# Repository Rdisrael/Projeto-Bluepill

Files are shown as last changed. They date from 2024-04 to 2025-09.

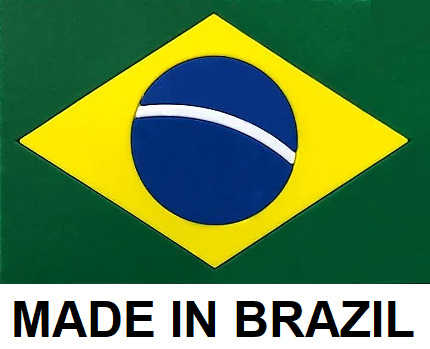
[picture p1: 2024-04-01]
ShieldBluepill V2/imagens e template/imagens/Brazil.jpg

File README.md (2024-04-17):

# PCB SHIELD BLUEPILL



# Resumo
Projeto idealizado com o objetivo de auxiliar as aulas de microcontroladores do IFSP-GRU. Por meio da integração de diversos módulos, componentes e protocolos de comunicação em apenas uma placa de circuito impresso, será possível um aprendizado mais rápido e gradual para os alunos.

# Documentação
https://docs.google.com/spreadsheets/d/1qsbzq-tmwSNhySCmtm99sBOb9c8ssFgKAU8AfdciUCU/edit?usp=sharing

*Salve o projeto no disco local(C:) para que todos os componentes e modelos 3D sejam automaticante carregados*

# Autores

**Rogério Dantas**

https://www.linkedin.com/in/roger-dantas-b04025137/

**Israel R. Dutra**

www.linkedin.com/in/israel-rodrigues-dutra-6947281a0

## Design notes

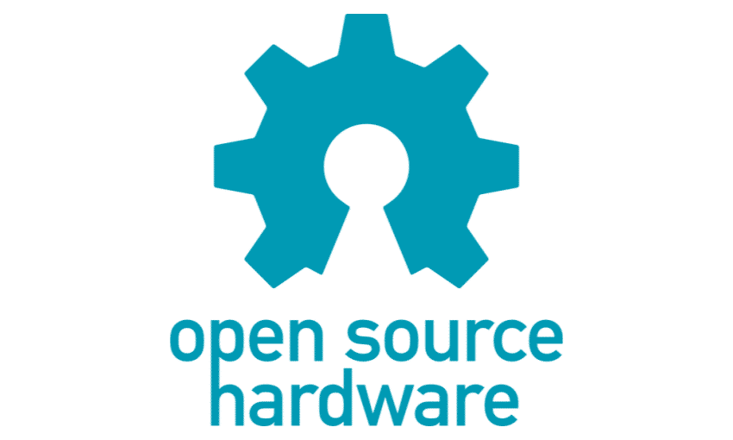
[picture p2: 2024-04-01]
ShieldBluepill V2/imagens e template/imagens/openhardware-destaque-850x510.png

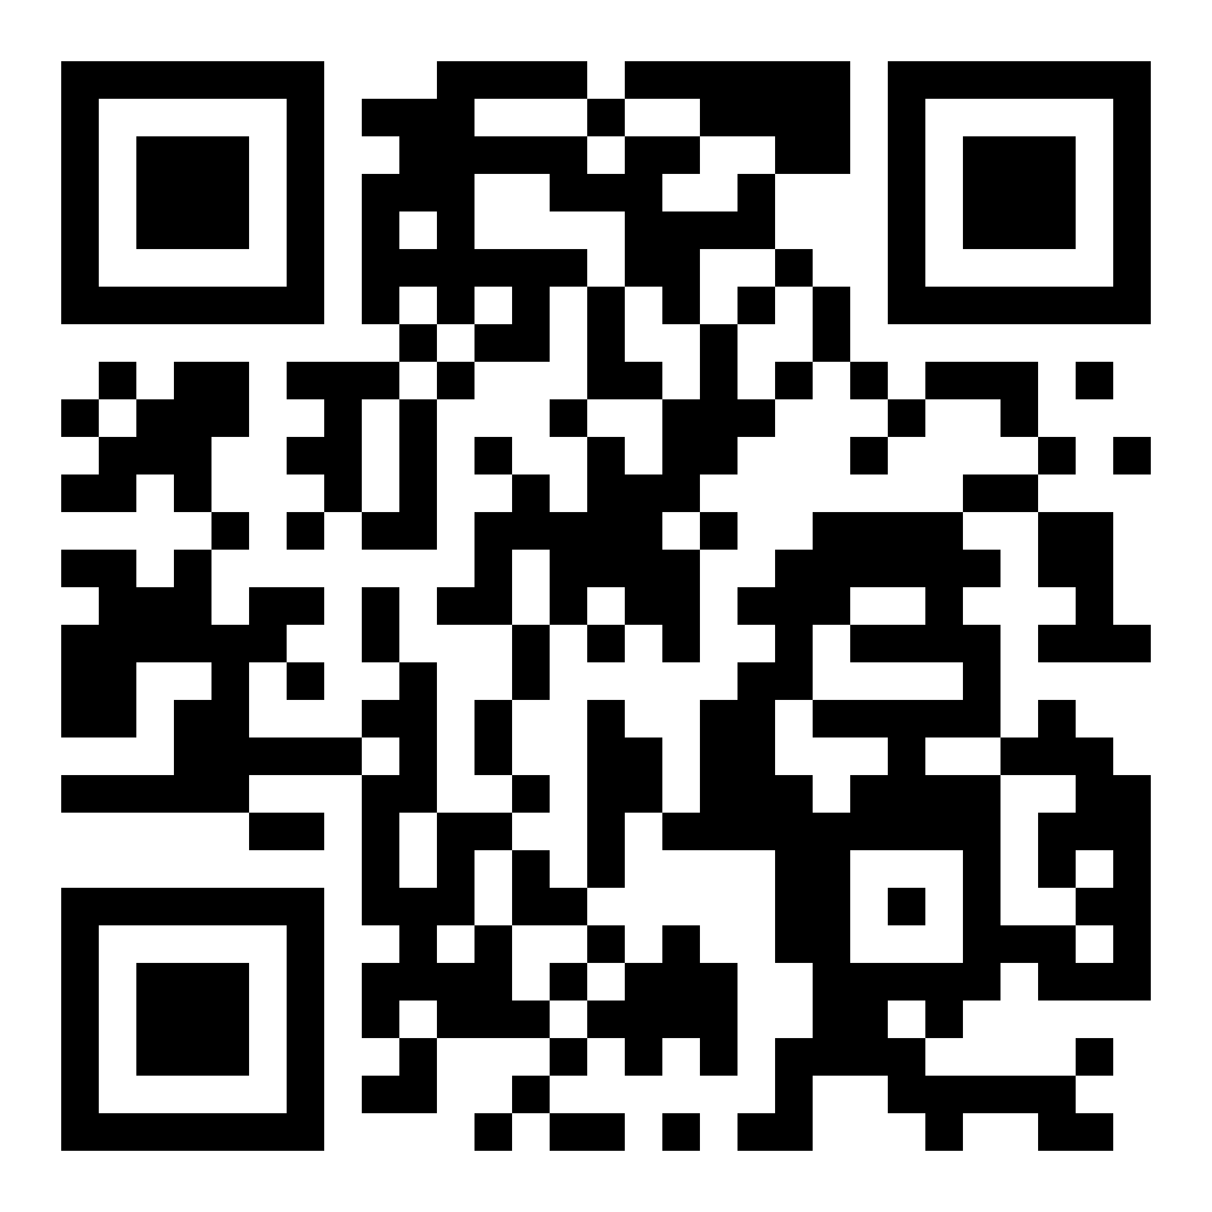
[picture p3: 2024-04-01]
ShieldBluepill V2/imagens e template/imagens/Bluepill GIT.png

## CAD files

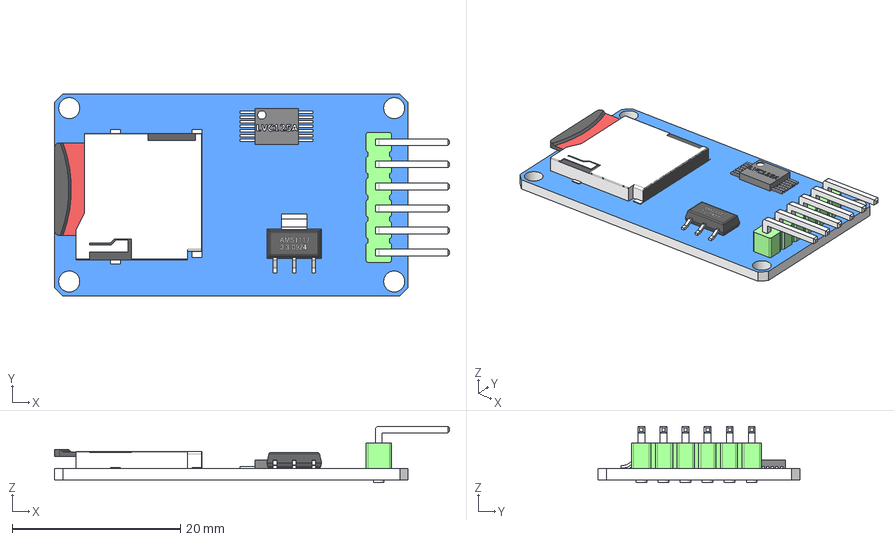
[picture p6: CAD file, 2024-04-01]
ShieldBluepill V2/Simbolo, pegada e modelo 3D/Modelos 3D/MicroSD Reader Assembly.stp
46.9 x 24.0 x 6.70 mm
sdreader
AMS1117
card sd

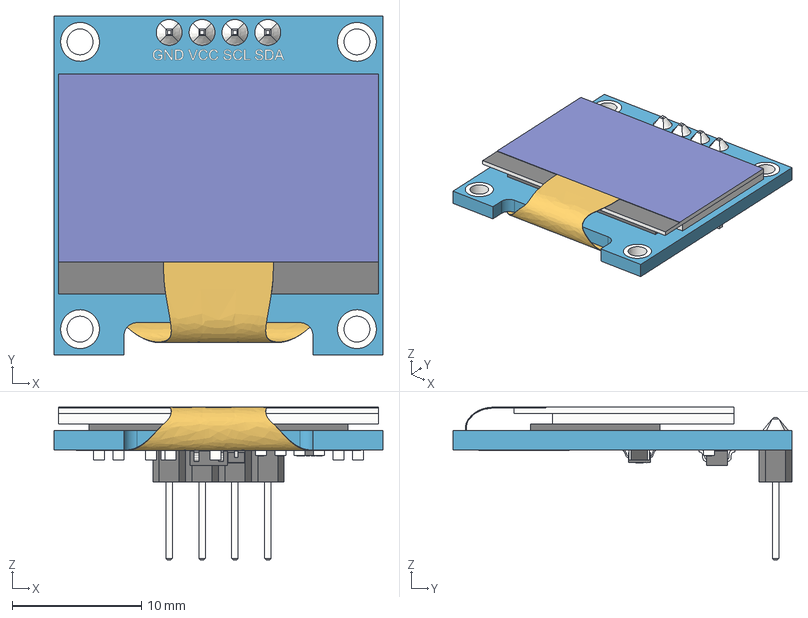
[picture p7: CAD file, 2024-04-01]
ShieldBluepill V2/Simbolo, pegada e modelo 3D/Modelos 3D/SSD1306_OLED_Display(128x64).step
25.4 x 26.2 x 11.8 mm
board
screen
pin_header
soldering
smd_capacitor
smd_capacitor (1)
914_smd_resistor
472_smd_resistor x 3
t4_smd_diode
smd_capacitor (2)
smd_capacitor (3)
smd_capacitor (4)
smd_capacitor (5)
smd_capacitor (6)
472_smd_resistor (1)
SOT-23_XC6206 v3
smd_capacitor (7)
flat_cable

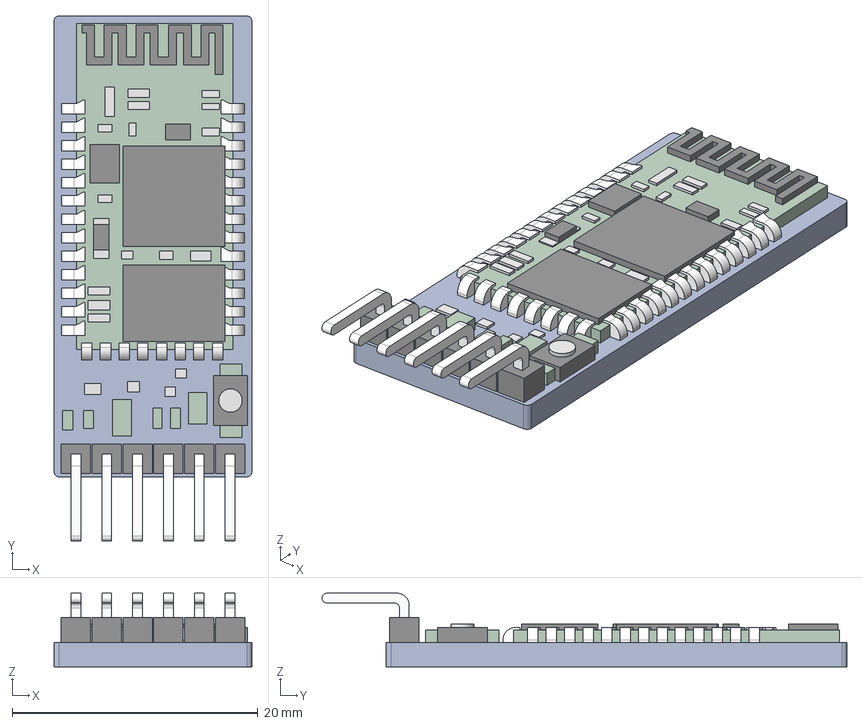
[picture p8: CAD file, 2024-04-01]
ShieldBluepill V2/Simbolo, pegada e modelo 3D/Modelos 3D/HC_05 Blue Tooth Module.stp
16.1 x 42.7 x 6.00 mm

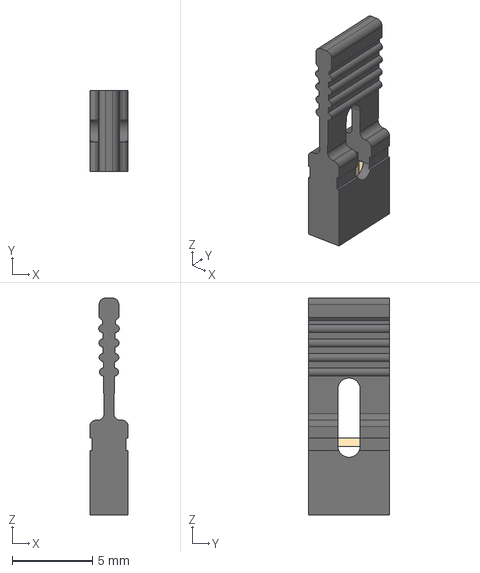
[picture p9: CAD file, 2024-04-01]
ShieldBluepill V2/Simbolo, pegada e modelo 3D/Modelos 3D/AKSPLTG-BLACK.stp
2.39 x 5.05 x 13.5 mm

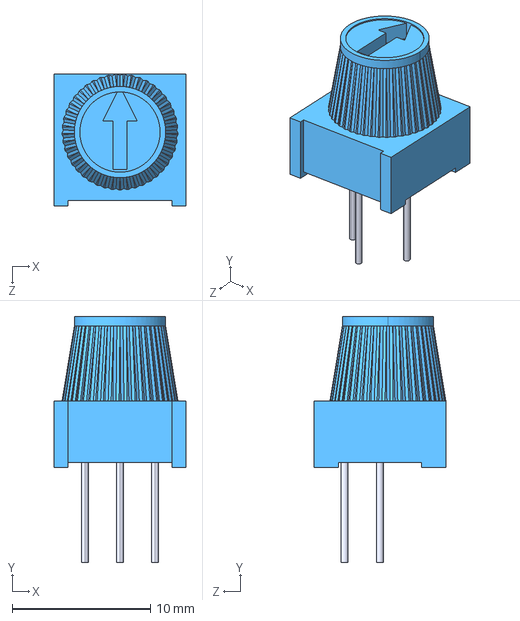
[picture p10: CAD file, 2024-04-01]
ShieldBluepill V2/Simbolo, pegada e modelo 3D/Modelos 3D/Potenciometro.STEP
9.53 x 17.8 x 9.53 mm

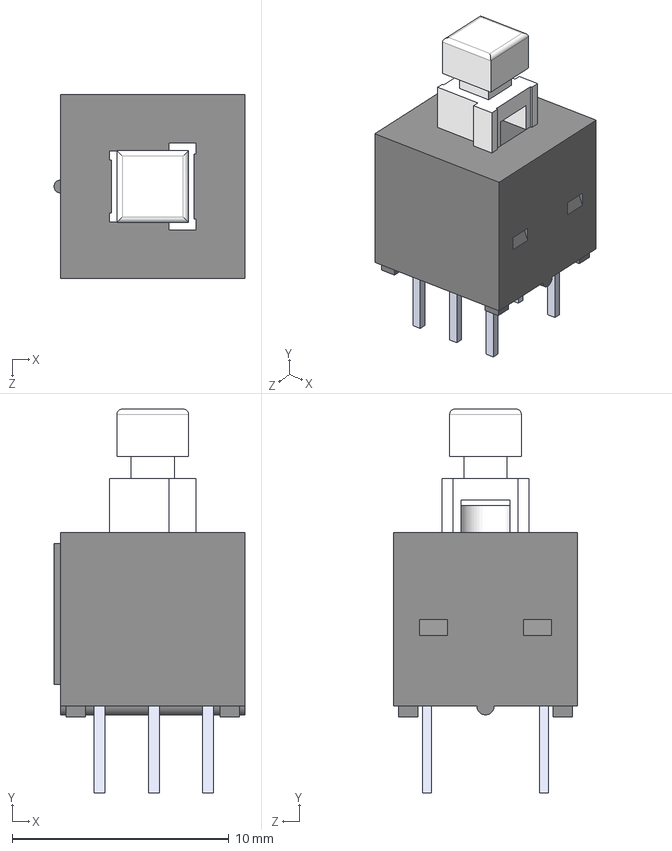
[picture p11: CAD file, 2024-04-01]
ShieldBluepill V2/Simbolo, pegada e modelo 3D/Modelos 3D/Botão com retenção.step
8.80 x 17.7 x 8.50 mm

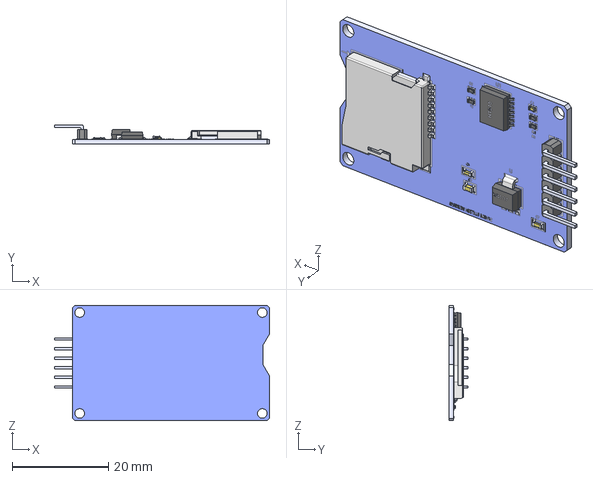
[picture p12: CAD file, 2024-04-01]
ShieldBluepill V2/Simbolo, pegada e modelo 3D/Modelos 3D/leitor microsd.step
44.7 x 4.00 x 24.0 mm

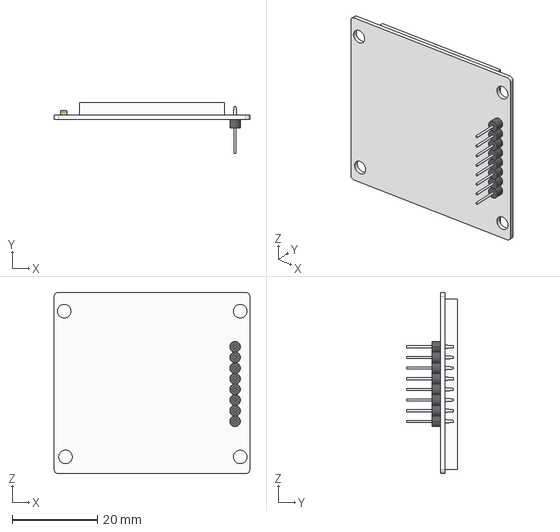
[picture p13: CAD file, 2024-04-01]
ShieldBluepill V2/Simbolo, pegada e modelo 3D/Modelos 3D/Nokia LCD.stp
46.0 x 12.0 x 42.5 mm

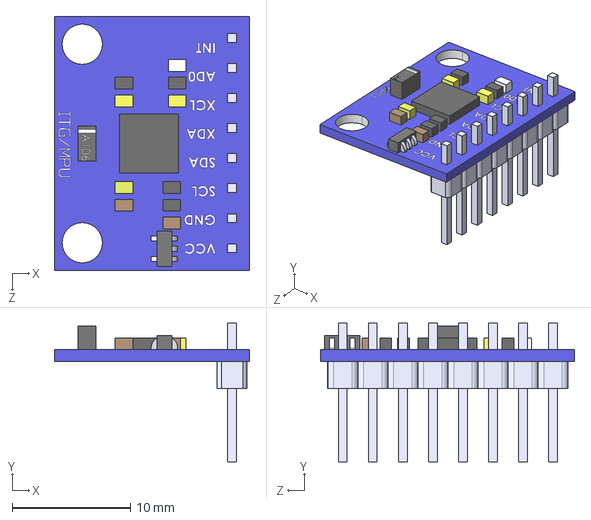
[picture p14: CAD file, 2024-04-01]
ShieldBluepill V2/Simbolo, pegada e modelo 3D/Modelos 3D/ITG-MPU.STEP
16.5 x 11.8 x 21.5 mm
8 Header-Pin
Placa_Base

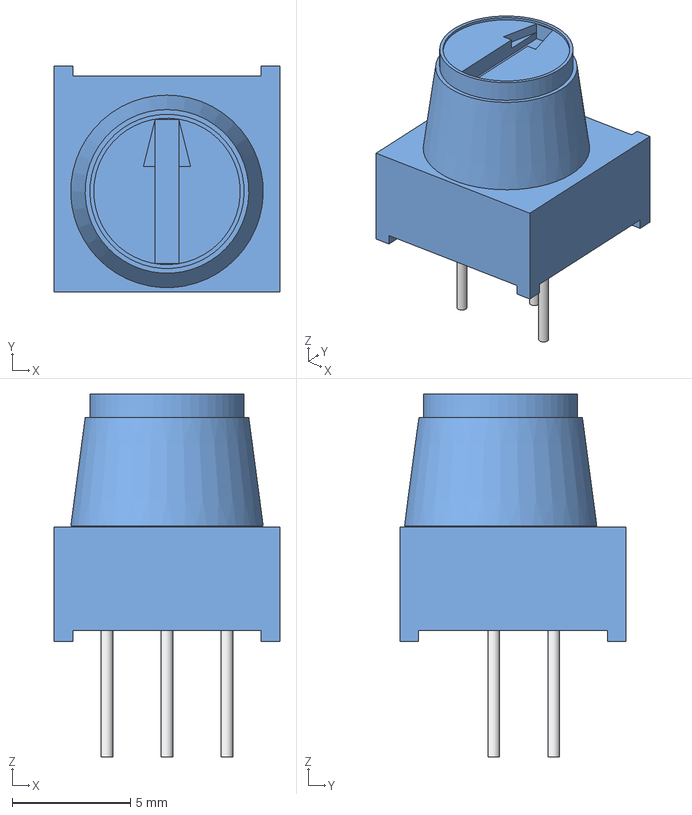
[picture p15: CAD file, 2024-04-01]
ShieldBluepill V2/Simbolo, pegada e modelo 3D/Modelos 3D/Trimpot with knob.step
9.55 x 9.55 x 15.4 mm
trimpot
knob

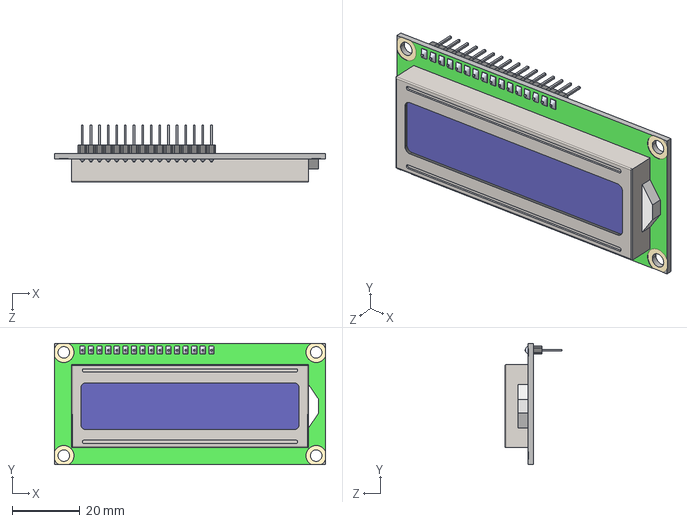
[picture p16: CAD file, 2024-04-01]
ShieldBluepill V2/Simbolo, pegada e modelo 3D/Modelos 3D/LCD 16X2.STEP
80.0 x 35.8 x 16.9 mm

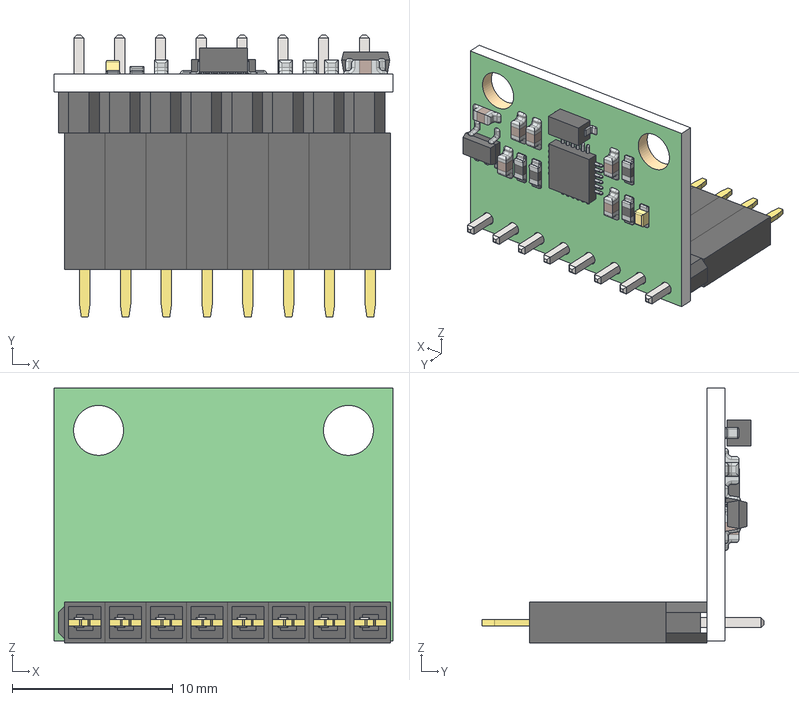
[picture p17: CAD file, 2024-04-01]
ShieldBluepill V2/Simbolo, pegada e modelo 3D/Modelos 3D/MPU-6050-on-female-header.step
21.1 x 17.6 x 15.9 mm
Base
pin header x 8
sensor chip
S2NH chip
Resistor small x 6
Resistor small black x 4
Small LED
Resistor black
SIL_Socket_Body x 8
SIL_SocketPin x 8

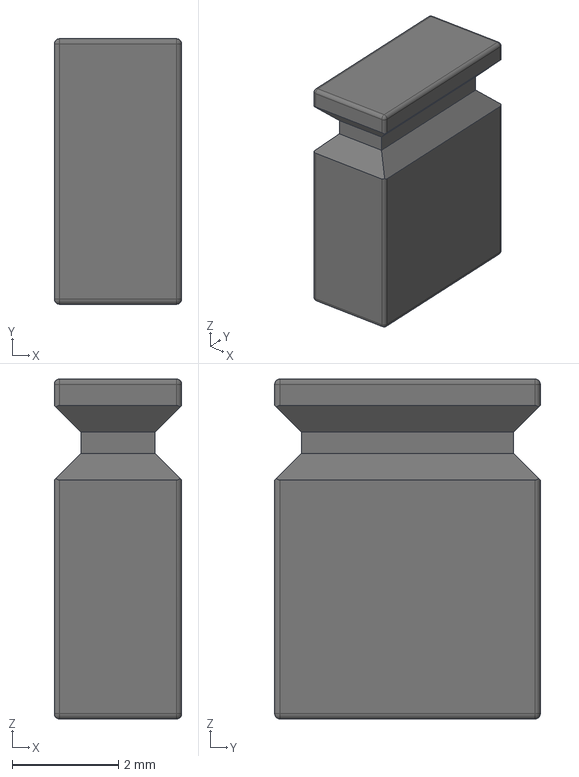
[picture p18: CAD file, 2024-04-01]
ShieldBluepill V2/Simbolo, pegada e modelo 3D/Modelos 3D/AKSCT-G-BLACK.stp
2.40 x 5.00 x 6.40 mm

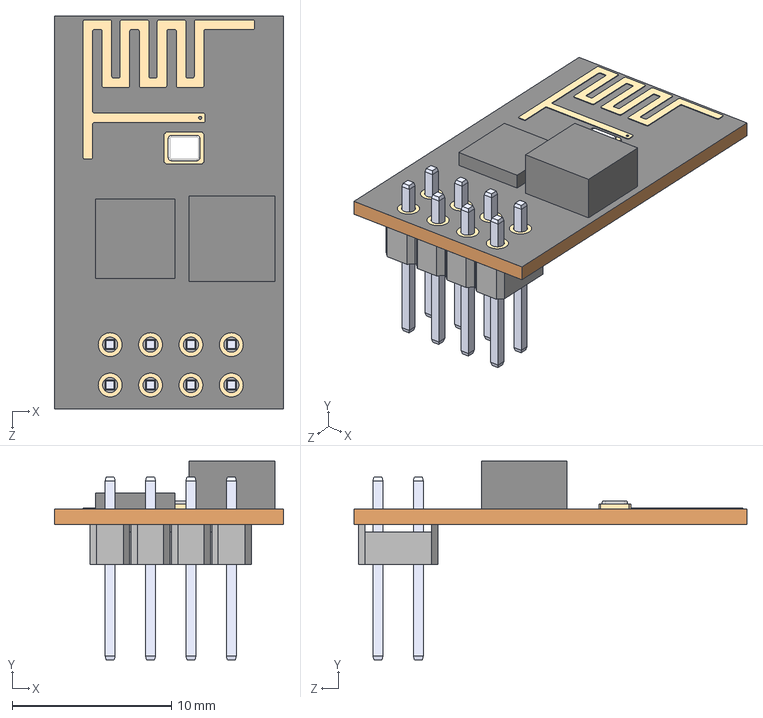
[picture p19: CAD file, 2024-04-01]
ShieldBluepill V2/Simbolo, pegada e modelo 3D/Modelos 3D/ESP-01.STEP
14.4 x 12.5 x 24.7 mm

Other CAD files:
ShieldBluepill V2/Simbolo, pegada e modelo 3D/Modelos 3D/micro-switch-7x7.step
ShieldBluepill V2/Simbolo, pegada e modelo 3D/Modelos 3D/ESP-01S_RevA.STEP

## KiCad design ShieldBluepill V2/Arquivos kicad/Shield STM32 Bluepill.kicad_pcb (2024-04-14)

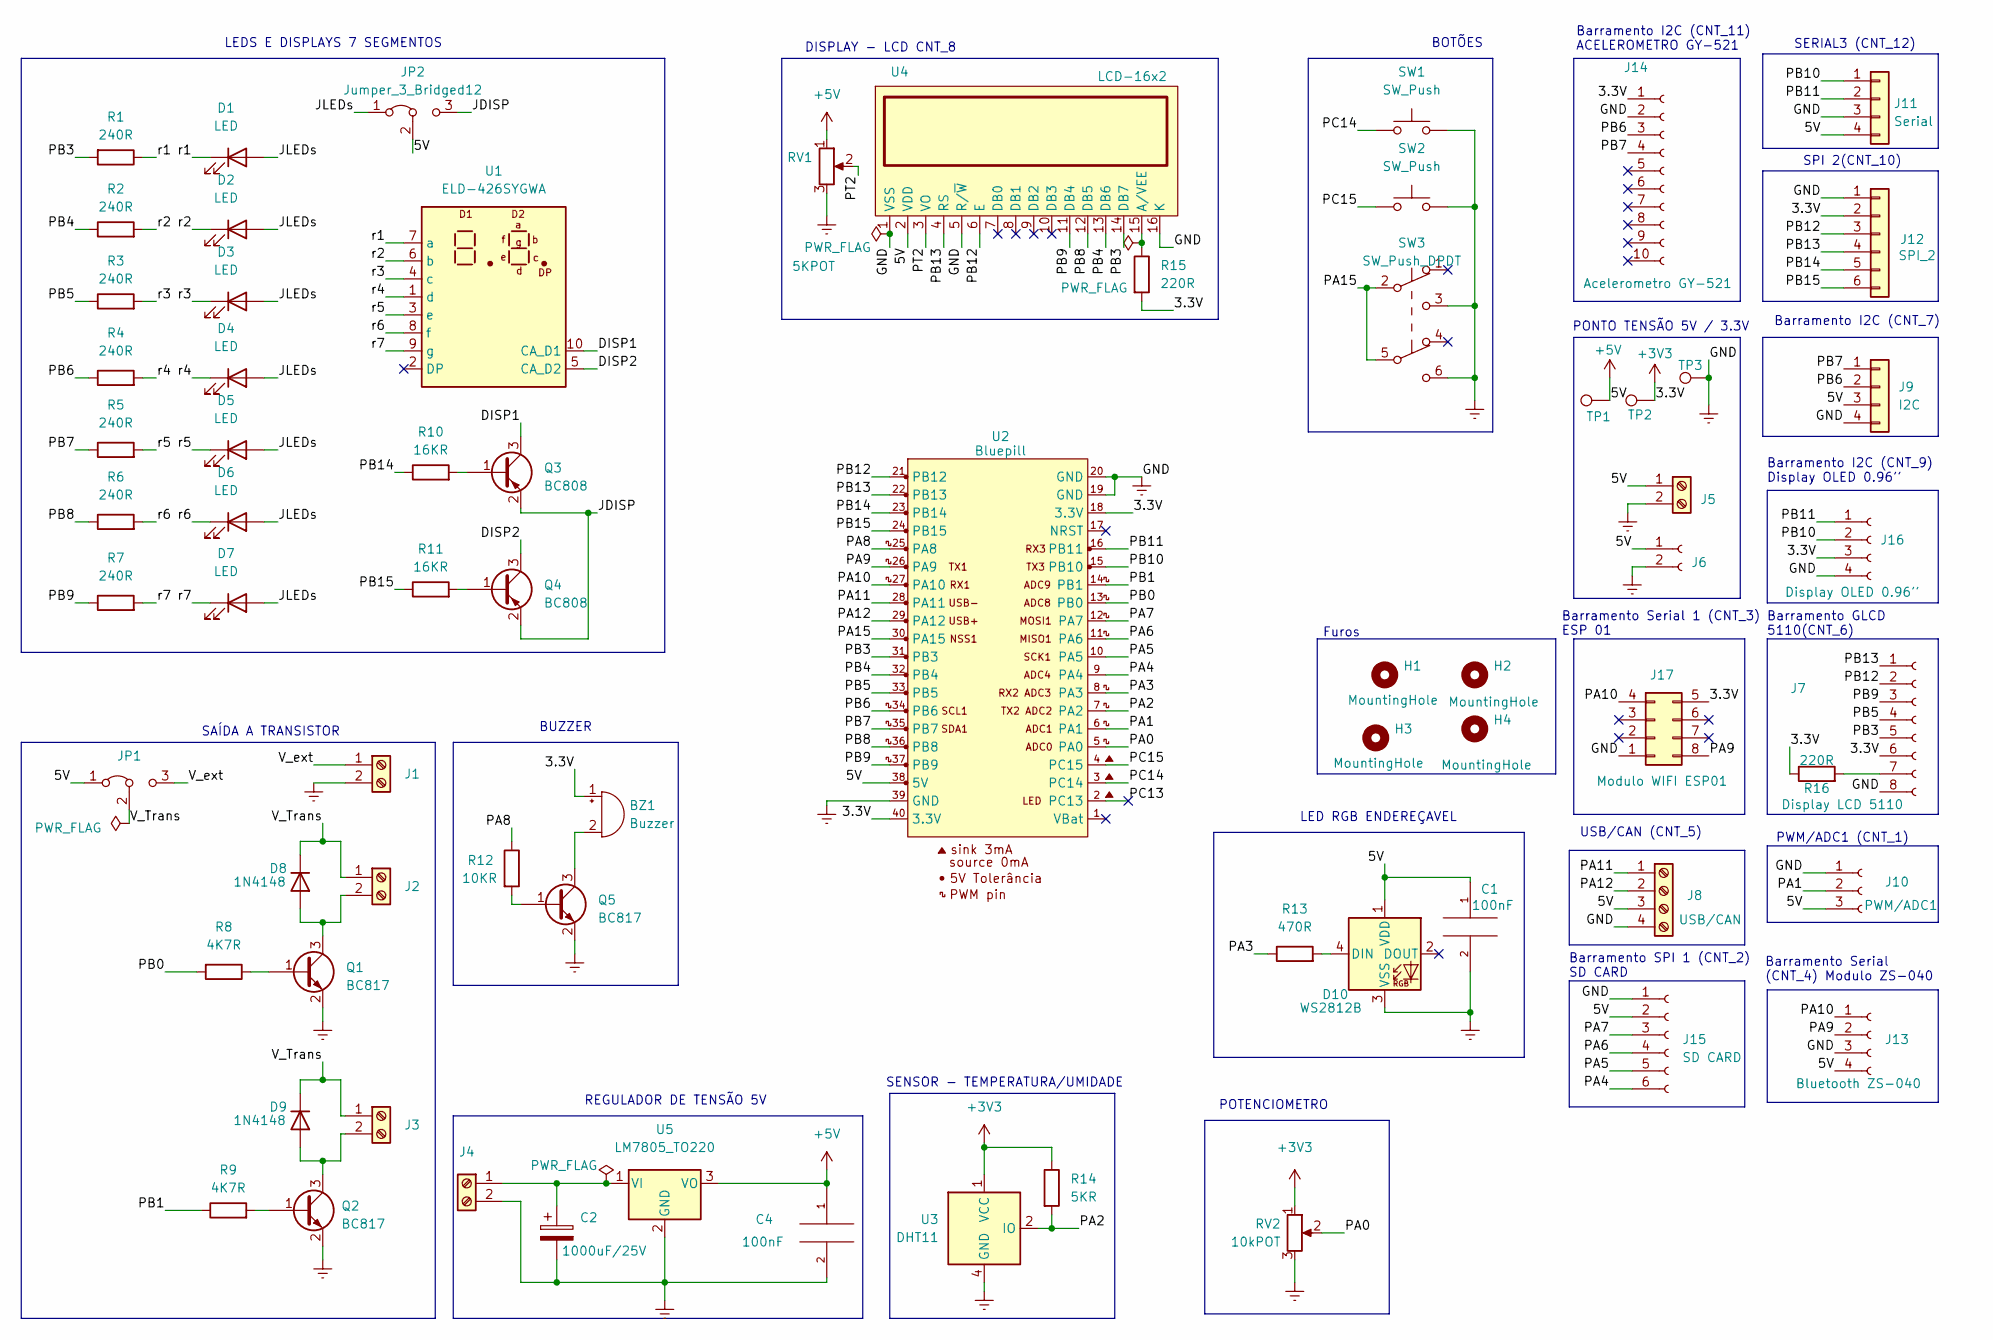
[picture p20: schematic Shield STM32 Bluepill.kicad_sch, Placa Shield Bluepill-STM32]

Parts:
BZ1: Buzzer; Buzzer_12x9.5RM7.6
C1, C4: 100nF; C_1206_3216Metric
C2: 1000uF/25V; CP_Elec_10x10
D1, D2, D3, D4, D5, D6, D7: LED; LED_1206_3216Metric
D8, D9: 1N4148; D_1206_3216Metric
D10: WS2812B; LED_WS2812B_PLCC4_5.0x5.0mm_P3.2mm
H1, H2, H3, H4: MountingHole; MountingHole_2.2mm_M2_Pad_Via
J1, J2, J3, J4, J5: Screw_Terminal_01x02; TerminalBlock_Phoenix_MKDS-1,5-2-5.08_1x02_P5.08mm_Horizont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
J6: Conn_01x02_Female; PinSocket_1x02_P2.54mm_Vertical
J7: Display LCD 5110; PinSocket_1x08_P2.54mm_Vertical
J8: USB/CAN; TerminalBlock_Phoenix_MKDS-1,5-4-5.08_1x04_P5.08mm_Horizont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
J9: I2C; Molex_KK-254_AE-6410-04A_1x04_P2.54mm_Vertical
J10: PWM/ADC1; PinSocket_1x03_P2.54mm_Vertical
J11: Serial; Molex_KK-254_AE-6410-04A_1x04_P2.54mm_Vertical
J12: SPI_2; Molex_KK-254_AE-6410-06A_1x06_P2.54mm_Vertical
J13: Bluetooth ZS-040; PinSocket_1x04_P2.54mm_Vertical
J14: Acelerometro GY-521; PinSocket_1x10_P2.54mm_Vertical
J15: SD CARD; PinSocket_1x06_P2.54mm_Vertical
J16: Display OLED 0.96''; PinSocket_1x04_P2.54mm_Vertical
J17: Modulo WIFI ESP01; PinSocket_2x04_P2.54mm_Vertical
JP1, JP2: Jumper_3_Bridged12; PinHeader_1x03_P2.54mm_Vertical
Q1, Q2, Q5: BC817; SOT-23
Q3, Q4: BC808; SOT-23
R1, R2, R3, R4, R5, R6, R7: 240R; R_1206_3216Metric
R8, R9: 4K7R; R_1206_3216Metric
R10, R11: 16KR; R_1206_3216Metric
R12: 10KR; R_1206_3216Metric
R13: 470R; R_1206_3216Metric
R14: 5KR; R_1206_3216Metric
R15, R16: 220R; R_1206_3216Metric
RV1: 5KPOT; Potentiometer_Bourns_3006P_Horizontal
RV2: 10kPOT; Potentiometer_Bourns_3339P_Vertical
SW1, SW2: SW_Push; SW_PUSH_6mm_H7.3mm
SW3: SW_Push_DPDT; SW_TL2201EEYA
TP1, TP2, TP3: TestPoint; TestPoint_Pad_4.0x4.0mm
U1: ELD-426SYGWA; ELD_426XXXX
U2: Bluepill; YAAJ_BluePill_SWD_1
U3: DHT11; Aosong_DHT11_5.5x12.0_P2.54mm
U4: LCD-16x2; WC1602A
U5: LM7805_TO220; TO-220-3_Vertical

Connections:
+3V3: BZ1.1 (-), J7.6, J12.2, J14.1, J16.3, J17.5, R14.1, R15.2, R16.1, RV2.1, TP2.1, U2.18 (3.3V), U2.40 (3.3V), U3.1 (VCC)
+5V: C1.1, C4.1, D10.1 (VDD), J5.1, J6.1, J8.3, J9.3, J10.3, J11.4, J13.4, J15.2, JP1.1 (A), JP2.2 (C), RV1.1, TP1.1, U2.38 (5V), U4.2 (VDD), U5.3 (VO)
/DISP1: Q3.3 (C), U1.10 (CA_D1)
/DISP2: Q4.3 (C), U1.5 (CA_D2)
/JDISP: JP2.3 (B), Q3.2 (E), Q4.2 (E)
/JLEDs: D1.2 (A), D2.2 (A), D3.2 (A), D4.2 (A), D5.2 (A), D6.2 (A), D7.2 (A), JP2.1 (A)
/PA0: RV2.2, U2.5 (PA0)
/PA1: J10.2, U2.6 (PA1)
/PA2: R14.2, U2.7 (PA2), U3.2 (IO)
/PA3: R13.1, U2.8 (PA3)
/PA4: J15.6, U2.9 (PA4)
/PA5: J15.5, U2.10 (PA5)
/PA6: J15.4, U2.11 (PA6)
/PA7: J15.3, U2.12 (PA7)
/PA8: R12.1, U2.25 (PA8)
/PA9: J13.2, J17.8, U2.26 (PA9)
/PA10: J13.1, J17.4, U2.27 (PA10)
/PA11: J8.1, U2.28 (PA11)
/PA12: J8.2, U2.29 (PA12)
/PA15: SW3.2 (B), SW3.5 (B), U2.30 (PA15)
/PB0: R8.2, U2.13 (PB0)
/PB1: R9.1, U2.14 (PB1)
/PB3: J7.5, R1.2, U2.31 (PB3), U4.14 (DB7)
/PB4: R2.1, U2.32 (PB4), U4.13 (DB6)
/PB5: J7.4, R3.1, U2.33 (PB5)
/PB6: J9.2, J14.3, R4.1, U2.34 (PB6)
/PB7: J9.1, J14.4, R5.1, U2.35 (PB7)
/PB8: R6.1, U2.36 (PB8), U4.12 (DB5)
/PB9: J7.3, R7.1, U2.37 (PB9), U4.11 (DB4)
/PB10: J11.1, J16.2, U2.15 (PB10)
/PB11: J11.2, J16.1, U2.16 (PB11)
/PB12: J7.2, J12.3, U2.21 (PB12), U4.6 (E)
/PB13: J7.1, J12.4, U2.22 (PB13), U4.4 (RS)
/PB14: J12.5, R10.1, U2.23 (PB14)
/PB15: J12.6, R11.1, U2.24 (PB15)
/PC13: U2.2 (PC13)
/PC14: SW1.1, U2.3 (PC14)
/PC15: SW2.1, U2.4 (PC15)
/PT2: RV1.2, U4.3 (VO)
/V_Trans: D8.1 (K), D9.1 (K), J2.1, J3.1, JP1.2 (C)
/V_ext: J1.1, JP1.3 (B)
/r1: D1.1 (K), R1.1, U1.7 (a)
/r2: D2.1 (K), R2.2, U1.6 (b)
/r3: D3.1 (K), R3.2, U1.4 (c)
/r4: D4.1 (K), R4.2, U1.1 (d)
/r5: D5.1 (K), R5.2, U1.3 (e)
/r6: D6.1 (K), R6.2, U1.8 (f)
/r7: D7.1 (K), R7.2, U1.9 (g)
Earth: C1.2, C2.2, C4.2, D10.3 (VSS), H1.1, H2.1, H3.1, H4.1, J1.2, J4.2, J5.2, J6.2, J7.8, J8.4, J9.4, J10.1, J11.3, J12.1, J13.3, J14.2, J15.1, J16.4, J17.1, Q1.2 (E), Q2.2 (E), Q5.2 (E), RV1.3, RV2.3, SW1.2, SW2.2, SW3.3 (C), SW3.6 (C), TP3.1, U2.19 (GND), U2.20 (GND), U2.39 (GND), U3.4 (GND), U4.1 (VSS), U4.5 (R/~W), U4.16 (K), U5.2 (GND)
unnamed: BZ1.2 (+), Q5.3 (C)
unnamed: D8.2 (A), J2.2, Q1.3 (C)
unnamed: D9.2 (A), J3.2, Q2.3 (C)
unnamed: D10.4 (DIN), R13.2
unnamed: C2.1, J4.1, U5.1 (VI)
unnamed: J7.7, R16.2
unnamed: Q1.1 (B), R8.1
unnamed: Q2.1 (B), R9.2
unnamed: Q3.1 (B), R10.2
unnamed: Q4.1 (B), R11.2
unnamed: Q5.1 (B), R12.2
unnamed: R15.1, U4.15 (A/VEE)

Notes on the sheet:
SAÍDA A TRANSISTOR
DISPLAY - LCD CNT_8
SENSOR - TEMPERATURA/UMIDADE
LEDS E DISPLAYS 7 SEGMENTOS
REGULADOR DE TENSÃO 5V
Barramento Serial (CNT_4) Modulo ZS-040
Barramento GLCD 5110(CNT_6)
BUZZER
POTENCIOMETRO
PWM/ADC1 (CNT_1)
SERIAL3 (CNT_12)
Furos
Barramento I2C (CNT_9) Display OLED 0.96''
SPI 2(CNT_10)
Barramento Serial 1 (CNT_3) ESP 01
Barramento SPI 1 (CNT_2) SD CARD
Barramento I2C (CNT_11) ACELEROMETRO GY-521
Barramento I2C (CNT_7)
LED RGB ENDEREÇAVEL
USB/CAN (CNT_5)
BOTÕES
PONTO TENSÃO 5V / 3.3V

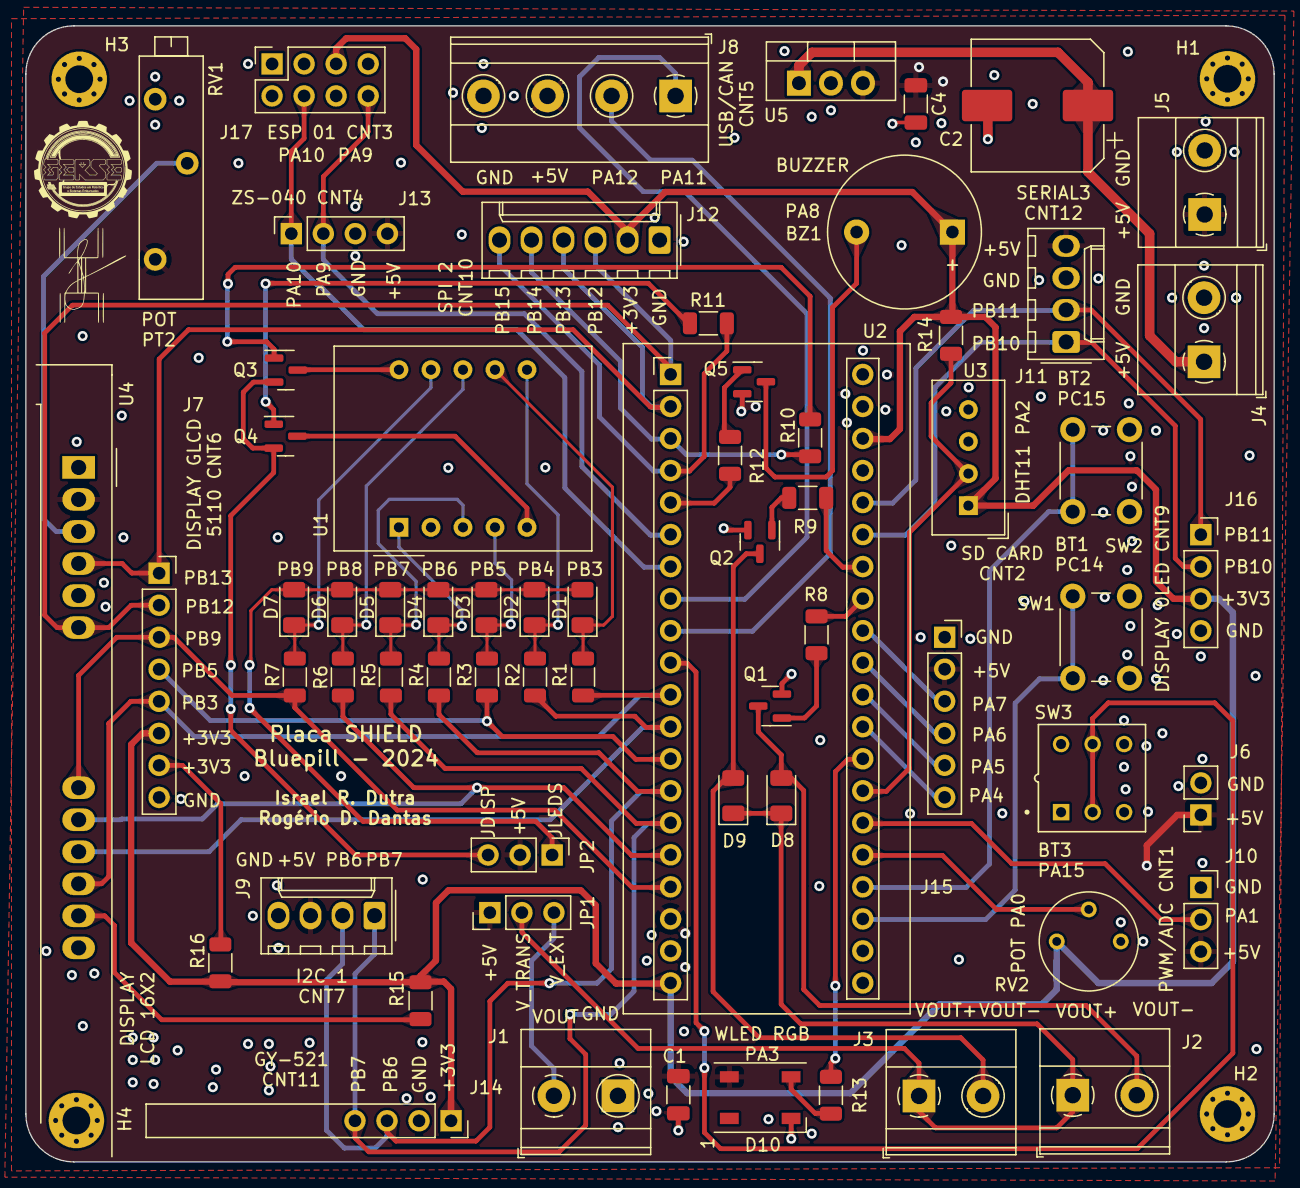
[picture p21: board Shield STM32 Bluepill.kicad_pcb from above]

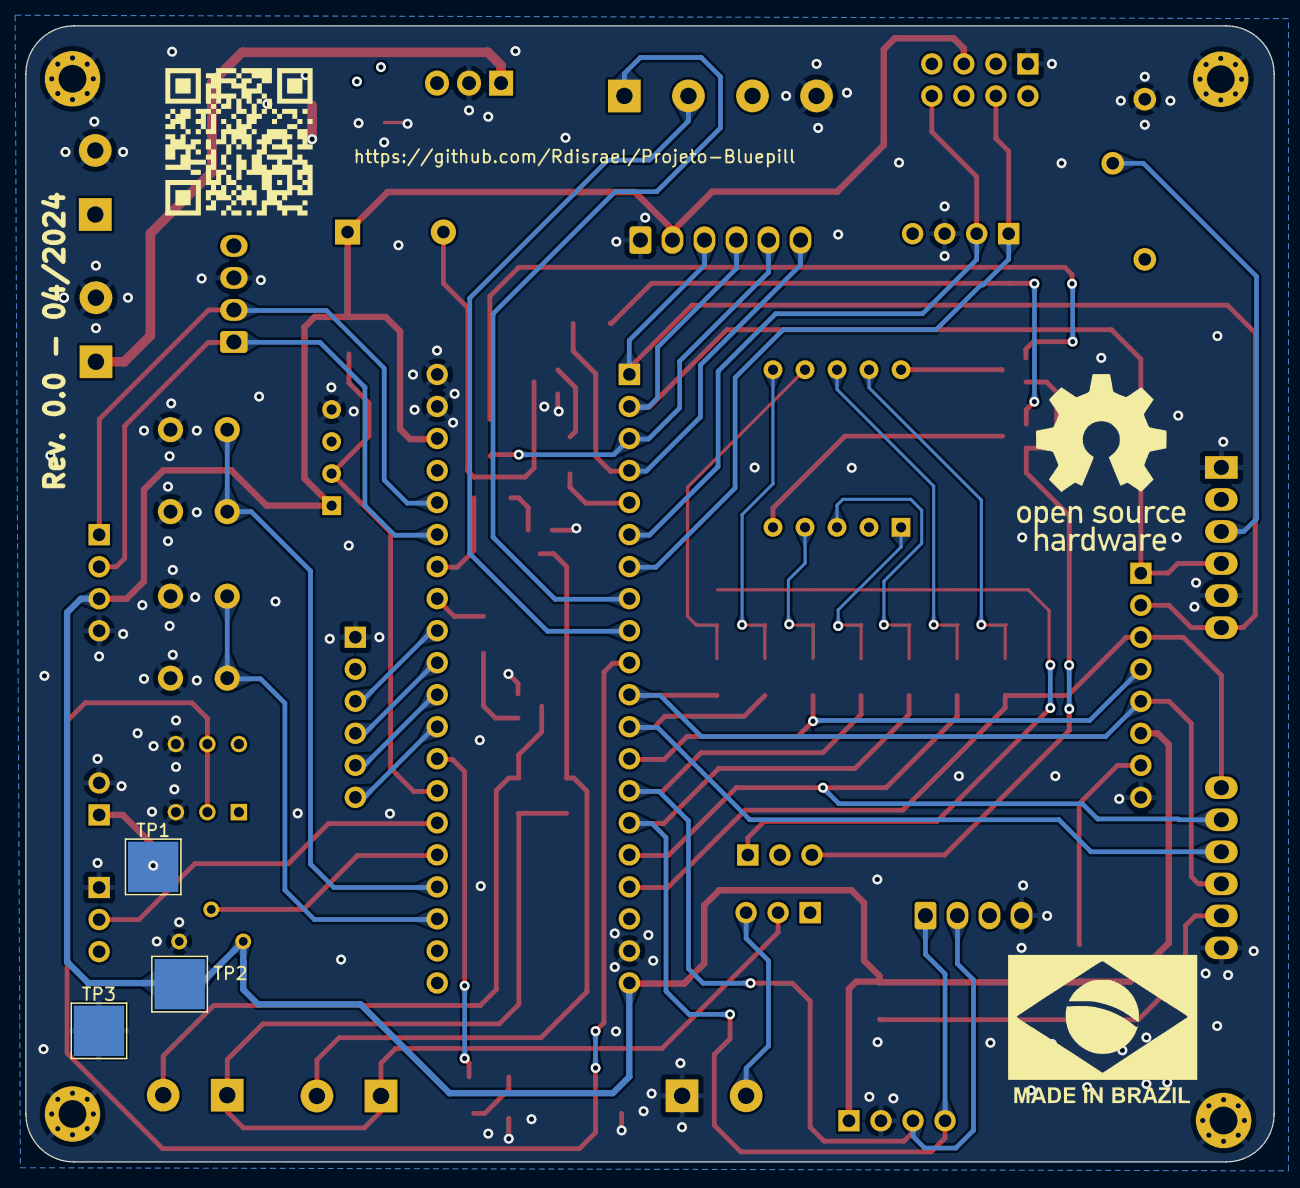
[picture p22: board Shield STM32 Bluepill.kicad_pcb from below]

Board: 2 copper layers, 99.0 x 90.1 mm, 71 parts (3 on the bottom side), 60 nets.

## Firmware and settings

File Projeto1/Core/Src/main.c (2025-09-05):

//1-controlar o pwm do buzzer utilizando o ADC do potenciômetro
//2-mostrar os dados do acelerometro no display oled alternar entre os valores de aceleração e rotação por meio do botão sw3
//3-apertando o botão sw2 deve gravar os valores do gy-521 no sd card
//4-apartando o sw1 deve se piscar os led e aparecer o autor no display
//5-som de inicio deve ser uma musica
/* USER CODE END Header */
/* Includes ------------------------------------------------------------------*/
#include "main.h"
#include "fatfs.h"
#include "ssd1306.h"
#include "fonts.h"
#include "gy521.h"
#include <stdio.h>
ADC_HandleTypeDef hadc1;
I2C_HandleTypeDef hi2c2;
SPI_HandleTypeDef hspi1;
TIM_HandleTypeDef htim1;
TIM_HandleTypeDef htim3;
void SystemClock_Config(void);
static void MX_GPIO_Init(void);
static void MX_ADC1_Init(void);
static void MX_TIM1_Init(void);
static void MX_TIM3_Init(void);
static void MX_I2C2_Init(void);
static void MX_SPI1_Init(void);
/* USER CODE BEGIN 0 */
void set_pwm_duty_from_adc(void) {//controle do pwm via adc
    HAL_ADC_Start(&hadc1);
    HAL_ADC_PollForConversion(&hadc1, HAL_MAX_DELAY);
    uint32_t adc_val = HAL_ADC_GetValue(&hadc1);
    HAL_ADC_Stop(&hadc1);

    uint32_t arr = __HAL_TIM_GET_AUTORELOAD(&htim1);
    uint32_t duty = (adc_val * arr) / 4095;

    __HAL_TIM_SET_COMPARE(&htim1, TIM_CHANNEL_1, duty);
}

void delay_ms(uint32_t ms) {//delay usando um contador do STM
    __HAL_TIM_SET_COUNTER(&htim3, 0);
    HAL_TIM_Base_Start(&htim3);
    while (__HAL_TIM_GET_COUNTER(&htim3) < ms);

    HAL_TIM_Base_Stop(&htim3);
}
void ledtest(void){//teste para ligar todos os leds da placa
		HAL_GPIO_TogglePin(GPIOC, GPIO_PIN_13);
		HAL_GPIO_TogglePin(GPIOB, GPIO_PIN_3);
		HAL_GPIO_TogglePin(GPIOB, GPIO_PIN_4);
		HAL_GPIO_TogglePin(GPIOB, GPIO_PIN_5);
		HAL_GPIO_TogglePin(GPIOB, GPIO_PIN_6);
		HAL_GPIO_TogglePin(GPIOB, GPIO_PIN_7);
		HAL_GPIO_TogglePin(GPIOB, GPIO_PIN_8);
		delay_ms(10000);
}

int nota (int hz){
int FREQ=72000000;
if (hz == 0) return 1;
return FREQ/(1000*hz);
}

void nothingelse(void) {//musica do buzzer pelo pwm
    int E = 82;
    int G = 196;
    int B = 247;
    int e = 330;

    __HAL_TIM_SET_PRESCALER(&htim1, nota(E));
    set_pwm_duty_from_adc();
    delay_ms(12000);

    __HAL_TIM_SET_PRESCALER(&htim1, nota(G));
    set_pwm_duty_from_adc();
    delay_ms(7000);

    __HAL_TIM_SET_PRESCALER(&htim1, nota(B));
    set_pwm_duty_from_adc();
    delay_ms(7000);

    __HAL_TIM_SET_PRESCALER(&htim1, nota(e));
    set_pwm_duty_from_adc();
    delay_ms(7000);

    __HAL_TIM_SET_PRESCALER(&htim1, nota(B));
    set_pwm_duty_from_adc();
    delay_ms(7000);

    __HAL_TIM_SET_PRESCALER(&htim1, nota(G));
    set_pwm_duty_from_adc();
    delay_ms(12000);
}
/* USER CODE END 0 */
FIL gyroFile;
char gyroFilename[] = "gyro_log.txt";
UINT bytesWritten;
/**
  * @brief  The application entry point.
  * @retval int
  */
int main(void)
{

  /* MCU Configuration--------------------------------------------------------*/

  /* Reset of all peripherals, Initializes the Flash interface and the Systick. */
  HAL_Init();

  /* Configure the system clock */
  SystemClock_Config();

  /* Initialize all configured peripherals */
  MX_GPIO_Init();
  MX_ADC1_Init();
  MX_TIM1_Init();
  MX_TIM3_Init();
  MX_I2C2_Init();
  MX_SPI1_Init();
  MX_FATFS_Init();
  /* USER CODE BEGIN 2 */

  SSD1306_Init();
  MPU6050_Init(&hi2c2);
  AxisRaw accel, gyro;
  /* USER CODE END 2 */

  /* Infinite loop */
  /* USER CODE BEGIN WHILE */
  while (1)
  {
  MPU6050_Read_Gyro(&hi2c2, &gyro);
  OLED_Show_GYRO(gyro);
  HAL_TIM_PWM_Start(&htim1, TIM_CHANNEL_1);
  nothingelse();
  delay_ms(500);
  if(HAL_GPIO_ReadPin(GPIOC, GPIO_PIN_14)==0){
	 HAL_TIM_PWM_Stop(&htim1, TIM_CHANNEL_1);
	 ledtest();
	 SSD1306_AUTOR();
	  delay_ms(5000);
  }
  if(HAL_GPIO_ReadPin(GPIOC, GPIO_PIN_15)==0){
	 HAL_TIM_PWM_Stop(&htim1, TIM_CHANNEL_1);
	 MPU6050_Read_Gyro(&hi2c2, &gyro);
	 char line[64];
	 snprintf(line, sizeof(line), "%ld %ld %ld\r\n",
	 (long)gyro.X,
	 (long)gyro.Y,
	 (long)gyro.Z);
	 if(f_open(&gyroFile, gyroFilename, FA_OPEN_ALWAYS | FA_WRITE) == FR_OK) {
		f_lseek(&gyroFile, f_size(&gyroFile)); // posiciona no fim
		f_write(&gyroFile, line, strlen(line), &bytesWritten);
		f_close(&gyroFile);
		}
     delay_ms(500);
   }
	if(HAL_GPIO_ReadPin(GPIOA, GPIO_PIN_15)==0){
	  HAL_TIM_PWM_Stop(&htim1, TIM_CHANNEL_1);
	  MPU6050_Read_Accel(&hi2c2, &accel);
	  OLED_Show_ACCEL(accel);
	  delay_ms(7000);
	}
}

}
  /* USER CODE END 3 */


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


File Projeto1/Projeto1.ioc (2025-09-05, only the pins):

Mcu.UserName=STM32F103C8Tx
PA0-WKUP.GPIO_Label=POT
PA0-WKUP.Signal=ADCx_IN0
PA13.Signal=SYS_JTMS-SWDIO
PA14.Signal=SYS_JTCK-SWCLK
PA15.GPIO_Label=SW3
PA15.Signal=GPIO_Input
PA4.Signal=GPIO_Output
PA5.Signal=SPI1_SCK
PA6.Signal=SPI1_MISO
PA7.Signal=SPI1_MOSI
PA8.GPIO_Label=BUZZER
PA8.Signal=S_TIM1_CH1
PA9.Signal=GPIO_Output
PB10.Signal=I2C2_SCL
PB11.Signal=I2C2_SDA
PB3.GPIO_Label=LED1
PB3.Signal=GPIO_Output
PB4.GPIO_Label=LED2
PB4.Signal=GPIO_Output
PB5.GPIO_Label=LED3
PB5.Signal=GPIO_Output
PB6.GPIO_Label=LED4
PB6.Signal=GPIO_Output
PB7.GPIO_Label=LED5
PB7.Signal=GPIO_Output
PB8.GPIO_Label=LED6
PB8.Signal=GPIO_Output
PB9.GPIO_Label=LED7
PB9.Signal=GPIO_Output
PC13-TAMPER-RTC.GPIO_Label=BOARD LED
PC13-TAMPER-RTC.Signal=GPIO_Output
PC14-OSC32_IN.GPIO_Label=SW1
PC14-OSC32_IN.Signal=GPIO_Input
PC15-OSC32_OUT.GPIO_Label=SW2
PC15-OSC32_OUT.Signal=GPIO_Input
PD0-OSC_IN.Signal=RCC_OSC_IN
PD1-OSC_OUT.Signal=RCC_OSC_OUT

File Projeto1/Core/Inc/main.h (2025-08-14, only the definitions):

#define BOARD_LED_Pin GPIO_PIN_13
#define BOARD_LED_GPIO_Port GPIOC
#define SW1_Pin GPIO_PIN_14
#define SW1_GPIO_Port GPIOC
#define SW2_Pin GPIO_PIN_15
#define SW2_GPIO_Port GPIOC
#define POT_Pin GPIO_PIN_0
#define POT_GPIO_Port GPIOA
#define BUZZER_Pin GPIO_PIN_8
#define BUZZER_GPIO_Port GPIOA
#define SW3_Pin GPIO_PIN_15
#define SW3_GPIO_Port GPIOA
#define LED1_Pin GPIO_PIN_3
#define LED1_GPIO_Port GPIOB
#define LED2_Pin GPIO_PIN_4
#define LED2_GPIO_Port GPIOB
#define LED3_Pin GPIO_PIN_5
#define LED3_GPIO_Port GPIOB
#define LED4_Pin GPIO_PIN_6
#define LED4_GPIO_Port GPIOB
#define LED5_Pin GPIO_PIN_7
#define LED5_GPIO_Port GPIOB
#define LED6_Pin GPIO_PIN_8
#define LED6_GPIO_Port GPIOB
#define LED7_Pin GPIO_PIN_9
#define LED7_GPIO_Port GPIOB

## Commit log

2024-04-01 Segunda versão Shield Bluepill
    [AKSCT-G-BLACK.stp, AKSPLTG-BLACK.stp, Botão com retenção.step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]
2024-04-14 REV 0.0
    [Shield STM32 Bluepill-B_Cu.gbl, Shield STM32 Bluepill-B_Mask.gbs, Shield STM32 Bluepill-B_Paste.gbp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]

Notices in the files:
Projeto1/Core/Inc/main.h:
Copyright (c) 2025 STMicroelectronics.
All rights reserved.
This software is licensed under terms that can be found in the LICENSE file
